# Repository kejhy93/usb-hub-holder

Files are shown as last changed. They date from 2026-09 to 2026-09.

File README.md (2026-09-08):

# USB Hub Holder

A parametric, print-in-place desk stand that holds a thin, flat USB hub
**upright** on your desk so the **USB-C socket on its bottom end** stays plugged
in and usable.

It's designed around a **right-angle ("dogleg") USB-C cable**: the plug drops
into a cavity under the hub, and the cable turns and leaves through **either
side** or straight down through the base. A **full-height slot in the front**
lets you reach in and pull the plug out without fighting it.

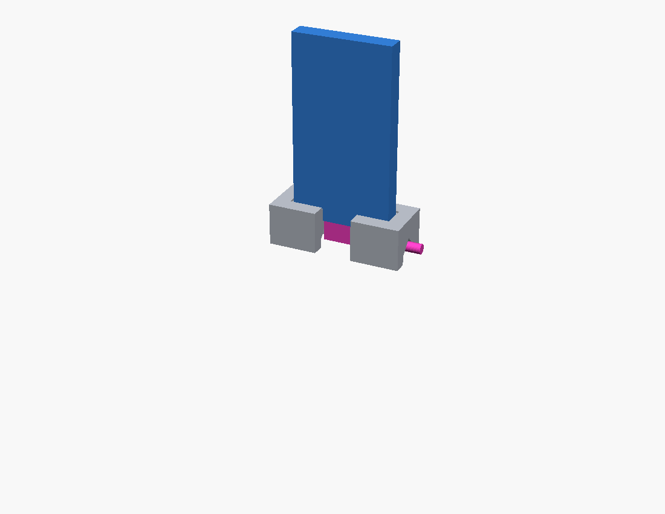
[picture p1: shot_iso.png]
preview


---

## Features

- **Fits your hub, not mine.** Every dimension is a parameter. "Flat stick"
  USB hubs all differ by a couple of millimetres — measure yours, type in the
  numbers, print.
- **No supports.** Prints flat, hub slot up. The block sits directly on the bed
  (no feet), the plug cavity is open top and bottom, the front slot runs
  straight through, and the only roof in the model is a 45° gable. There is no
  horizontal internal face anywhere.
- **Easy to unplug.** The plug is held only by the hub's own socket — the
  holder gives it clearance on all sides and opens the whole front.
- **No hardware.** No glue, no screws, no magnets. Just the print.

Default size: **80 × 32 × 25 mm** block; a 110 mm hub stands ~100 mm proud.

---

## How it works

```
  SIDE view                         FRONT view
                                     ___________________
       ___                          |   ___________     |
      |   |  hub stands             |  |    hub    |    |
      |   |  vertically,            |  |___________|    |
      |   |  USB-C socket           |  |         |  |== cable exits
      |___|  pointing DOWN          |  |  front  |  |   the side (or
     __| |__   right-angle          |  |  slot   |  |   down, or the
    |plug   |  USB-C plug           |  |         |  |   other side)
    |_______|                       |__|         |___|
       | |___  cable turns          |____|_______|____|
                                     block sits flat on the desk
```

- The hub drops into a slot in the top; it rests on two internal ledges and is
  held front-to-back by the slot walls.
- The plug hangs into a cavity below. That cavity is open through the base, and
  a channel carries the turned cable out through both side faces.
- The front slot removes the middle of the front wall over the plug, full
  height, so you can grab the plug. The block stays rigid: the sides are solid
  and the back wall ties them together.

---

## Fitting your hub

Open `hub_holder.scad` in [OpenSCAD](https://openscad.org/). Use
**Window → Customizer**, or edit the values at the top of the file.

### 1. Measure the hub

Calipers, take the **largest** reading — include any moulding seam or the lip
around the socket.

| Parameter | What to measure |
|---|---|
| `hub_width` | long side of the rectangular end |
| `hub_thickness` | short side of the rectangular end |
| `hub_length` | tip to tip (on-screen preview only) |

### 2. Measure the right-angle plug on your cable

| Parameter | What to measure |
|---|---|
| `plug_body_width` | plug body, across the hub's **wide** axis |
| `plug_body_thickness` | plug body, across the hub's **thin** axis |
| `plug_body_height` | how far the plug + strain relief hangs below the hub |
| `cable_diameter` | the bare cable just past the plug |

### 3. Render (F6), export STL (F7), print.

The console prints the resulting outer size, slot opening, and how far the hub
will stick up.

---

## All parameters

### Hub

| Parameter | Default | Notes |
|---|---:|---|
| `hub_width` | 59 | long side of the end |
| `hub_thickness` | 11 | short side of the end |
| `hub_length` | 110 | preview only, not critical |

### Right-angle USB-C cable plug

| Parameter | Default | Notes |
|---|---:|---|
| `plug_body_width` | 21 | across the hub's wide axis |
| `plug_body_thickness`  | 10 | across the hub's thin axis |
| `plug_body_height` | 16 | drop below the hub |
| `cable_diameter` | 6 | bare cable |
| `cable_channel_height` | 13 | side channel height — taller = easier finger access|
| `front_slot_width` | 22 | front access slot width; `0` closes the front |

### Holder body

| Parameter | Default | Notes |
|---|---:|---|
| `block_width`  | 80 | wider = more stable side to side |
| `block_depth`  | 32 | deeper = harder to tip forward/back |
| `pocket_depth` | 9 | how far the hub sinks in; more = firmer grip |

### Fit and finish

| Parameter | Default | Notes |
|---|---:|---|
| `hub_clearance` | 0.4 | total slack in the hub slot (both sides). See below. |
| `plug_clearance` | 2.0 | slack around the plug — keep loose so only the socket grips it |
| `channel_extra_width` | 4 | extra width in the side cable channel |
| `mouth_chamfer` | 1.2 | lead-in around the top of the hub slot |
| `retention_nub` | 0 | tiny bumps that pinch the hub so it doesn't rattle |

### Quality

| Parameter | Default | Notes |
|---|---:|---|
| `fn` | 48 | curve resolution |

---

## Printing

| | |
|---|---|
| **Orientation** | as modelled — flat on the bed, hub slot facing up |
| **Supports** | none (see *Features*) |
| **Material** | PLA or PETG |
| **Infill** | ~15–20 % — the mass is what keeps it from tipping |
| **Layer height**| anything; 0.2 mm is fine |

---

## Troubleshooting

**The hub doesn't fit / rattles.** Change only `hub_clearance` and reprint. FDM
printers shrink slots, so some slack is always needed.

- won't go in → raise it (`0.6`, then `0.8`)
- rattles → lower it (`0.3`, then `0.2`), or add a little `retention_nub`

**A tall hub feels tippy.** Increase `block_depth` (front-to-back is the weak
direction) and/or `pocket_depth` for a firmer grip.

**The plug is hard to pull out.** The holder shouldn't grip the plug at all —
only the hub's socket should. Raise `plug_clearance` (`2.5`, then `3`). You can
also widen `front_slot_width` and `cable_channel_height` for more finger room.

**A parameter combination doesn't make sense.** The script `assert()`s with a
plain-language message telling you which value to change.

---

## Repository

| File | Purpose |
|---|---|
| `hub_holder.scad` | the model — the only file you need |
| `hub_holder.stl` | ready-to-slice mesh at the default parameters |
| `hub_holder.3mf` | same, project format |
| `preview_scene.scad` | coloured holder + mock hub + mock plug, for renders  |
| `shots.sh` | renders the preview PNGs (Linux, flatpak OpenSCAD) |
| `render_stl.py` | no-GPU STL→PNG fallback previewer (trimesh + matplotlib) |

### Rendering previews

```sh
# STL only (headless):
flatpak run org.openscad.OpenSCAD -o hub_holder.stl hub_holder.scad

# PNG previews:
./shots.sh
```

---

## Contributing / remixing

Issues and PRs welcome — especially fit numbers for specific hub models.
Remixes are encouraged; a link back is appreciated.

## License

[CC BY 4.0](https://creativecommons.org/licenses/by/4.0/) — use it, sell prints
of it, remix it; just credit the source.

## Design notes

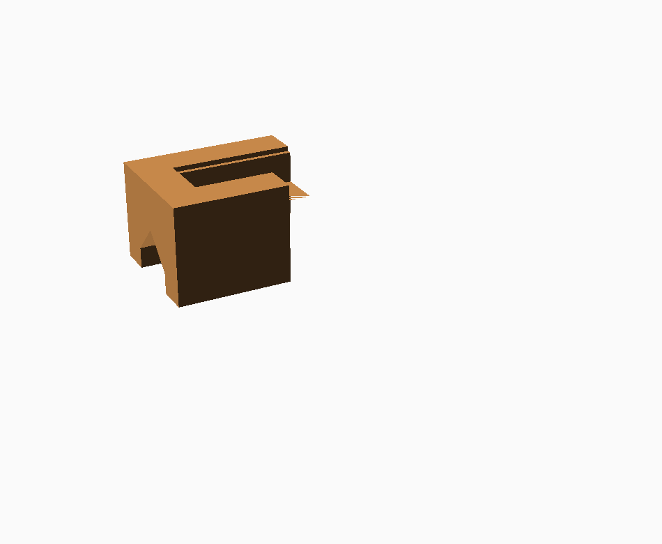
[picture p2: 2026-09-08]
shot_section.png

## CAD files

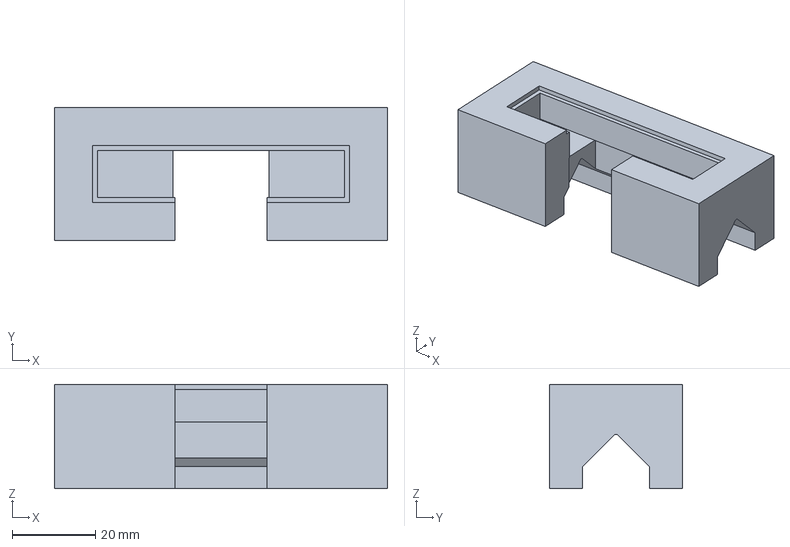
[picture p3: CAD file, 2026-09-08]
hub_holder.3mf
80.0 x 32.0 x 25.0 mm

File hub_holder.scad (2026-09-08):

// ============================================================================
//  Parametric desk stand for a flat USB hub  (right-angle / "dogleg" USB-C cable)
// ============================================================================
//
//  A small solid block that holds a thin, flat USB hub upright on your desk so
//  the USB-C socket on its BOTTOM end stays plugged in and usable. Designed for
//  a right-angle USB-C cable: the plug drops into a cavity under the hub and the
//  cable turns and leaves through either side (or straight down).
//
//  There are lots of near-identical "flat stick" USB hubs with slightly
//  different sizes, so everything is parametric - measure yours and type the
//  numbers into the parameters below (OpenSCAD Customizer, or edit the file).
//
//  ---------------------------------------------------------------------------
//  WHAT TO MEASURE  (calipers; take the largest reading, incl. any moulding
//  seam or lip around the socket)
//  ---------------------------------------------------------------------------
//
//   SIDE view                        FRONT view
//                                     ___________________
//        ___                         |   ___________     |
//       |   |  hub (stands            |  |    hub    |    |
//       |   |  vertically, USB-C      |  |___________|    |
//       |   |  socket pointing        |  |         |  |=  |=  cable exits
//       |___|  DOWN)                  |  |  front  |  |   |   the side
//      __| |__   plug_body_*          |  |  slot   |  |   |
//     |plug   |  (right-angle         |  |         |  |   |
//     |_______|   USB-C plug)         |__|         |___|
//        | |___  cable turns          |____|_______|____|
//                                      block sits flat on the desk
//         (the front slot runs the full height, straight through - no roof)
//
//  ---------------------------------------------------------------------------
//  PRINTING
//  ---------------------------------------------------------------------------
//    * Orientation: as modelled — flat on the bed, hub slot facing up.
//    * Supports: NONE. The block sits flat (no feet), the plug cavity is open
//      top and bottom, the front access slot runs straight through top to
//      bottom (no roof), and the cable channel roof is a 45-deg gable. There
//      is no horizontal internal face anywhere.
//    * Material: PLA/PETG both fine. ~15-20% infill; the mass helps it not tip.
//    * If the hub is a tight or loose fit, adjust `hub_clearance` (see notes
//      there) and reprint — no other change needed.
//
//  ---------------------------------------------------------------------------
//  License: CC-BY 4.0  —  attribution appreciated, commercial use allowed.
//  ============================================================================


/* [Hub - measure the USB hub you want to hold] */

// Hub WIDTH: the long side of the rectangular end (mm)
hub_width = 59;         // [10:0.5:120]
// Hub THICKNESS: the short side of the rectangular end (mm)
hub_thickness = 11;     // [3:0.5:30]
// Hub LENGTH: tip to tip. Not critical - only used for the on-screen preview
hub_length = 110;       // [20:200]


/* [Right-angle USB-C cable plug] */

// Plug body WIDTH - across the hub's wide axis, i.e. parallel to hub_width (mm)
plug_body_width = 21;        // [6:0.5:40]
// Plug body THICKNESS - across the hub's thin axis, parallel to hub_thickness (mm)
plug_body_thickness = 10;    // [4:0.5:20]
// Plug body HEIGHT - how far the plug + strain relief hangs below the hub (mm)
plug_body_height = 16;       // [6:40]
// Cable DIAMETER - the bare cable just past the plug (mm)
cable_diameter = 6;          // [2:0.5:12]
// Height of the side channel the turned cable escapes through (mm). Taller =
// easier to get a finger in from the side to pull the plug out.
cable_channel_height = 13;    // [4:30]
// FRONT access slot: opens the whole front of the plug cavity (full height,
// straight through) so you can grab the plug to unplug it. Width in mm across
// the hub; 0 = no slot. Because it runs top-to-bottom it has no roof, so it
// needs no support.
front_slot_width = 22;       // [0:40]


/* [Holder body] */

// Overall WIDTH of the block (mm). Wider = more stable side to side.
block_width = 80;            // [30:200]
// Overall DEPTH of the block, front to back (mm). Deeper = harder to tip
// forward/back - increase this if a tall hub feels wobbly.
block_depth = 32;            // [16:80]
// How far the hub sinks into the block (mm). More = firmer grip, taller print.
pocket_depth = 9;            // [4:40]


/* [Fit and finish] */

// Total clearance added to the hub slot, split over both sides (mm).
// FDM printers shrink slots, so some is always needed. Start ~0.4; if the hub
// won't go in, go to 0.6-0.8; if it rattles, drop to 0.2-0.3.
hub_clearance = 0.4;         // [0:0.05:1.5]
// Total clearance around the plug body cavity (mm). Keep this loose - the hub
// socket should be what grips the plug, not the holder. 2 mm is a good start;
// raise it if the plug is still hard to pull out.
plug_clearance = 2.0;        // [0:0.1:4]
// Extra width added to the side cable channel beyond the plug (mm, total). More
// room for a finger / for the cable to move.
channel_extra_width = 4;     // [0:0.5:15]
// Lead-in chamfer around the mouth of the hub slot (mm)
mouth_chamfer = 1.2;         // [0:0.1:4]
// Retention bump on each side of the slot so the hub doesn't rattle (mm of
// interference per side). 0 = none. Raise for a light "click"; lower it back
// to 0 if you then can't seat the hub.
retention_nub = 0;           // [0:0.05:1]


/* [Quality] */

// Curve resolution (higher = smoother nubs/preview, slower)
fn = 48;                     // [16:8:120]


/* [Hidden] */

$fn = fn;
eps = 0.02;                  // tiny overlap to keep booleans clean

// ---- derived slot / cavity sizes -------------------------------------------
slot_w = hub_width     + hub_clearance;     // hub slot opening (X)
slot_d = hub_thickness + hub_clearance;     // hub slot opening (Y)

cav_w  = plug_body_width     + plug_clearance;   // plug cavity, across width (X)
cav_d  = plug_body_thickness + plug_clearance;   // plug cavity, front-to-back (Y)

// ---- heights (Z, 0 = desk surface; block sits flat) ----------------------
total_h   = plug_body_height + pocket_depth;  // overall height
cav_top_z = plug_body_height;                 // where the plug cavity meets the slot

// side cable channel: at least as tall as the cable, capped so a ledge remains
channel_h = min(max(cable_channel_height, cable_diameter + 1), cav_top_z - 2);
// side channel depth (Y): the plug cavity plus finger room
channel_d = cav_d + channel_extra_width;

// front access slot width, capped so the hub keeps front wall + ledge each side
front_slot_w = (front_slot_width > 0) ? min(front_slot_width, slot_w - 16) : 0;

// ---- positions (Y, 0 = front face, block_depth = back face) --------------
cav_y0    = (block_depth - cav_d) / 2;      // plug cavity, centred in the depth
cav_y1    = cav_y0 + cav_d;
ch_y0     = (block_depth - channel_d) / 2;  // side channel, same centre, wider
ch_y1     = ch_y0 + channel_d;
slot_cy   = block_depth / 2;                // hub slot sits above the cavity
slot_y0   = slot_cy - slot_d / 2;
slot_y1   = slot_cy + slot_d / 2;

// ---- sanity checks --------------------------------------------------------
assert(block_width  >= slot_w + 6,
       "block_width is too small for this hub - increase block_width");
assert(block_depth  >= channel_d + 6,
       "block_depth is too small for the cable channel - increase block_depth or reduce channel_extra_width");
assert(block_depth  >= slot_d + 4,
       "block_depth is too small for the hub slot - increase block_depth");
assert(cav_d >= cable_diameter,
       "plug_body_thickness is too small for the cable - the cable channel would pinch it");

echo(str("Holder outer size  : ", block_width, " x ", block_depth,
         " x ", total_h, " mm (W x D x H)"));
echo(str("Hub slot opening   : ", slot_w, " x ", slot_d, " mm"));
echo(str("Hub sticks up ~    : ", hub_length - pocket_depth, " mm above the slot"));


// ============================================================================
//  Geometry
// ============================================================================

// Solid block that everything is cut from. Sits flat on the desk - no feet, so
// there is no overhang underneath to support.
module block_body() {
    translate([-block_width/2, 0, 0])
        cube([block_width, block_depth, total_h]);
}

// The slot the hub drops into, plus a chamfered lead-in at the top.
module hub_slot() {
    translate([-slot_w/2, slot_y0, cav_top_z])
        cube([slot_w, slot_d, pocket_depth + eps]);
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

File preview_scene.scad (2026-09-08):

// Assembled visual check: holder + mock hub + mock right-angle plug, coloured.
// Not for printing. Render with shots.sh. Set SECTION=true to cut the near half.

NO_AUTO_RENDER = true;
include <hub_holder.scad>

SECTION = is_undef(SECTION) ? false : SECTION;

hub_bottom_z = total_h - pocket_depth;

module mock_hub() {
    translate([-hub_width/2, slot_cy - hub_thickness/2, hub_bottom_z])
        cube([hub_width, hub_thickness, hub_length]);
}

module mock_plug() {
    body_h = min(plug_body_height, 12);
    zc = hub_bottom_z - body_h + cable_diameter/2 + 1;   // cable centre height
    // straight-down plug body under the hub
    translate([-plug_body_width/2, slot_cy - plug_body_thickness/2, hub_bottom_z - body_h])
        cube([plug_body_width, plug_body_thickness, body_h]);
    // dogleg: cable turns 90 deg and runs out the RIGHT side (left is symmetric)
    hull() {
        translate([0, slot_cy, zc]) rotate([0, 90, 0])
            cylinder(d = cable_diameter, h = eps);
        translate([block_width/2 + 8, slot_cy, zc]) rotate([0, 90, 0])
            cylinder(d = cable_diameter, h = eps);
    }
}

module scene() {
    color([0.72, 0.74, 0.78]) holder();
    color([0.20, 0.50, 0.85]) mock_hub();
    color([0.95, 0.25, 0.75]) mock_plug();
}

if (SECTION)
    difference() { scene(); translate([0, -60, -60]) cube([60, 160, 260]); }
else
    scene();

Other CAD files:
hub_holder.stl

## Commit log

2026-09-08 OpenSCAD file for hub holder
    [hub_holder.scad]
2026-09-08 STL file of hub holder
    [hub_holder.stl]
2026-09-08 3mf file of hub holder
    [hub_holder.3mf]
2026-09-08 Helper scripts
    [preview_scene.scad]
